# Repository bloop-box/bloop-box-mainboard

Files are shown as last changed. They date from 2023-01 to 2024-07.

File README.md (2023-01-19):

# Bloop Box Mainboard



Mainboard 3D Render

[Documentation](https://bloop-box.github.io/bloop-box-mainboard)

The board is designed using KiCAD 6 with production and assembly by JLCPCB in mind. All parts are selected to be
available from JLCPCB at the time of writing and as many parts as possible are used from their basic library.

- uHAT format (fits on a Raspberry Pi Zero)
- Connectors for:
  - Tailboard (Power supply, buttons, LEDs)
  - SPI NFC-reader (Pinout fitting for *RC522* Module)
  - Speaker
  - I2C connector for LED-Board
  - Additional GPIO header with UART (optional)
- Speaker is driven by a MAX98357 3W amplifier
  - amplifier gain can be set through jumper (9dB default setting)
  - SD_MODE is set to stereo mix by default, solder jumper for setting left-only 

Pinout of all connectors is printed on the bottom of the board

See schematics for detailed GPIO pinout

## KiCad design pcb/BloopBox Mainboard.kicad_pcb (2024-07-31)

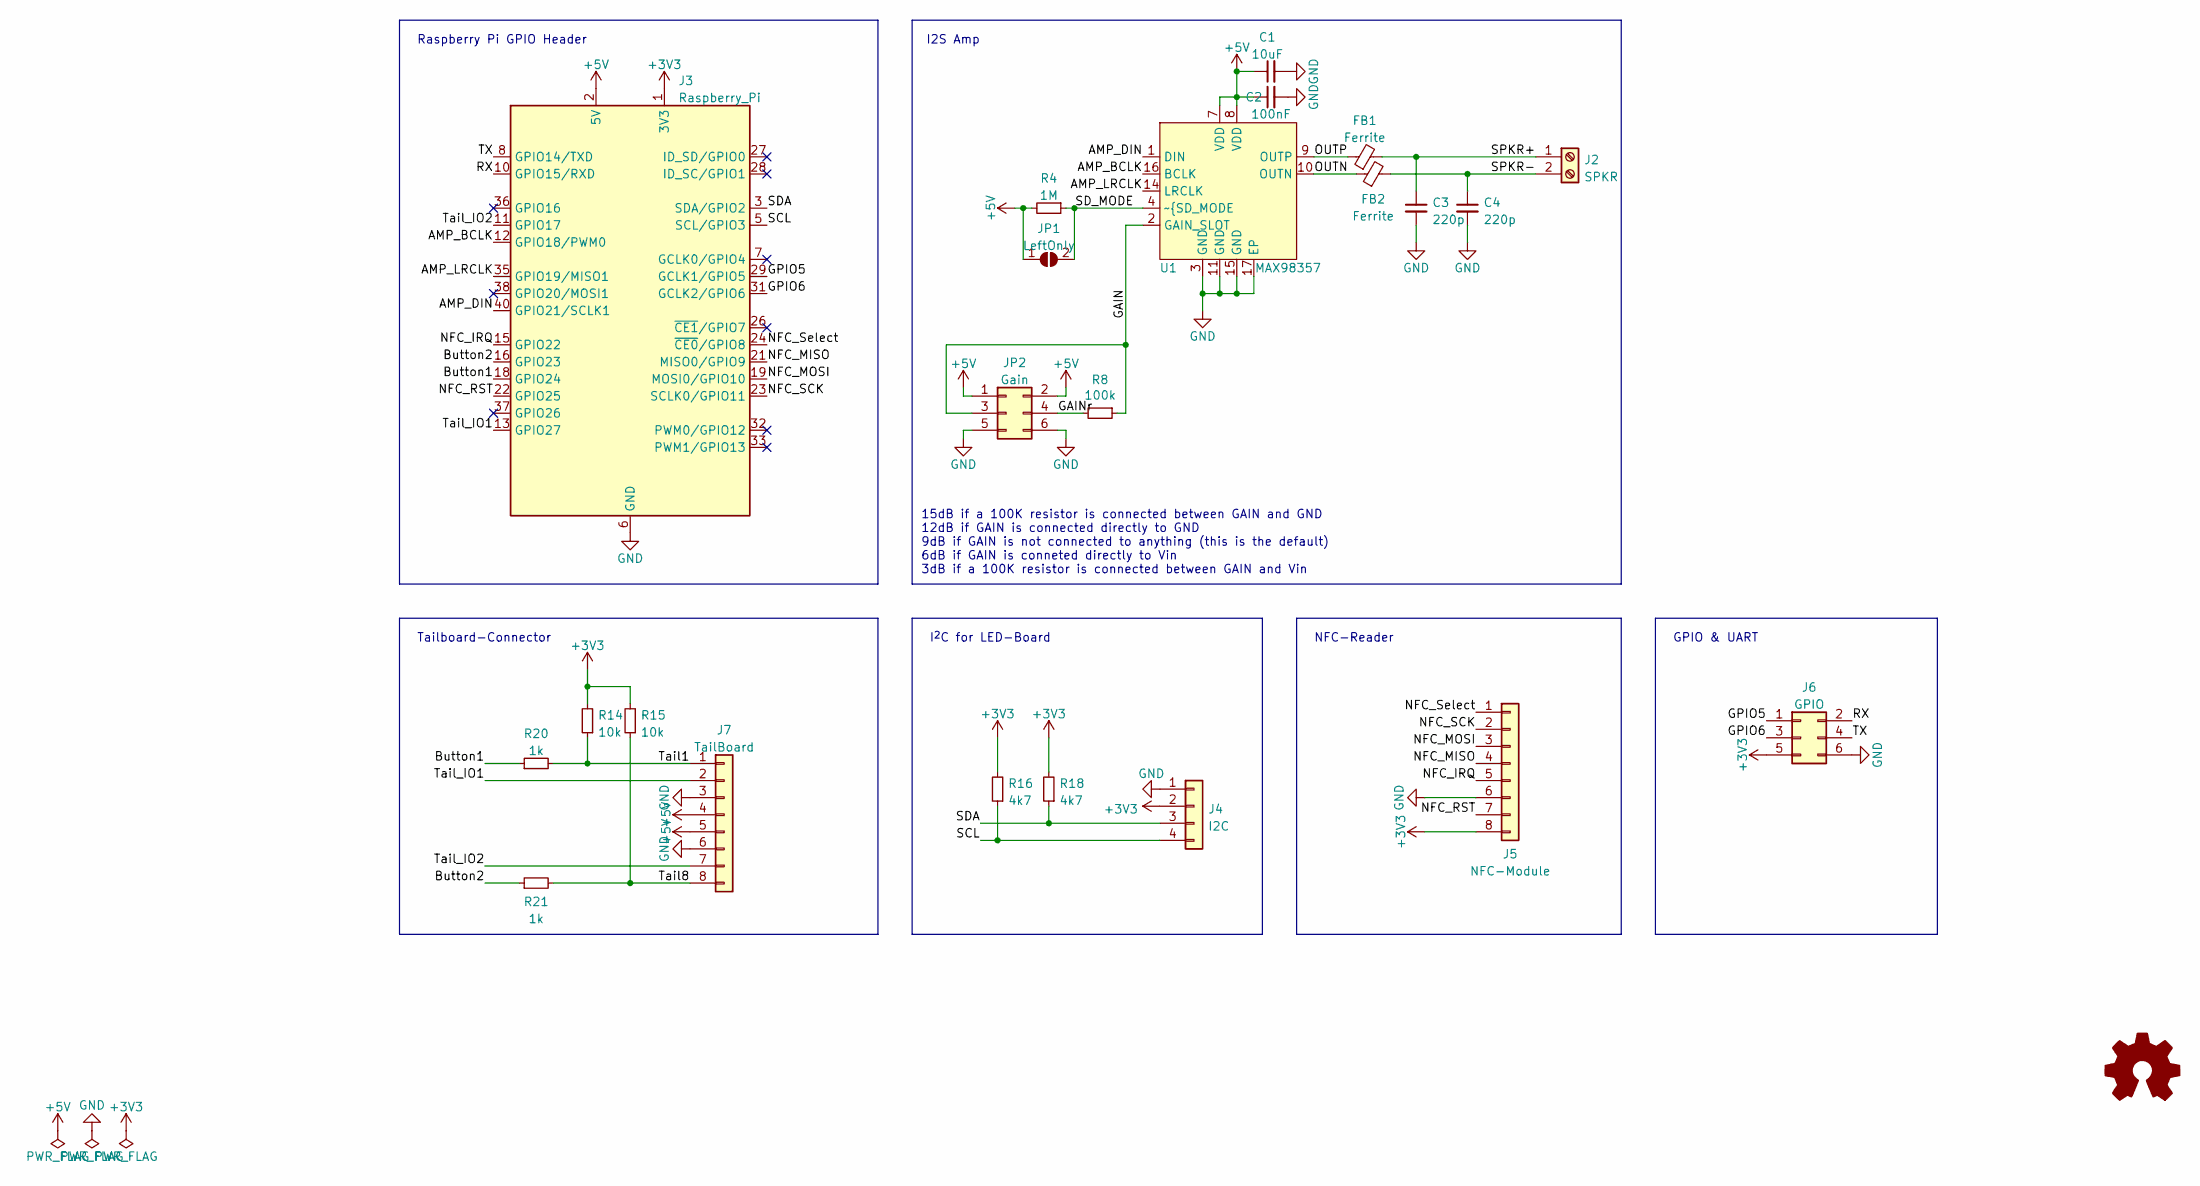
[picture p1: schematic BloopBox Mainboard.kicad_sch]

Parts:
C1: 10uF; C_0805_2012Metric; LCSC C15850
C2: 100nF; C_0402_1005Metric; LCSC C1525
C3, C4: 220p; C_0402_1005Metric; LCSC C1530
FB1, FB2: Ferrite; L_0805_2012Metric; LCSC C1015
J2: SPKR; JST_PH_S2B-PH-K_1x02_P2.00mm_Horizontal; LCSC C49992
J3: Raspberry_Pi; Raspberry_Pi_Zero_Socketed_THT_FaceDown_MountingHoles; LCSC C2977589
J4: I2C; JST_PH_S4B-PH-K_1x04_P2.00mm_Horizontal; LCSC C49994
J5: NFC-Module; JST_PH_S8B-PH-K_1x08_P2.00mm_Horizontal; LCSC C20598766
J6: GPIO; PinHeader_2x03_P2.54mm_Horizontal; LCSC C239334
J7: TailBoard; JST_PH_S8B-PH-K_1x08_P2.00mm_Horizontal; LCSC C20598766
JP1: LeftOnly; SolderJumper-2_P1.3mm_Open_RoundedPad1.0x1.5mm
JP2: Gain; PinHeader_2x03_P2.00mm_Vertical; LCSC C225288
R4: 1M; R_0402_1005Metric; LCSC C26083
R8: 100k; R_0402_1005Metric; LCSC C25741
R14, R15: 10k; R_0402_1005Metric; LCSC C25744
R16, R18: 4k7; R_0402_1005Metric; LCSC C25900
R20, R21: 1k; R_0402_1005Metric; LCSC C11702
U1: MAX98357; TQFN-16-1EP_3x3mm_P0.5mm_EP1.23x1.23mm_ThermalVias; LCSC C910544

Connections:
+3V3: J3.1 (3V3), J3.17 (3V3), J4.2, J5.8, J6.5, R14.2, R15.2, R16.2, R18.2
+5V: C1.1, C2.1, J3.2 (5V), J3.4 (5V), J7.4, J7.5, JP1.1 (A), JP2.1, JP2.2, R4.2, U1.7 (VDD), U1.8 (VDD)
/AMP_BCLK: J3.12 (GPIO18/PWM0), U1.16 (BCLK)
/AMP_DIN: J3.40 (GPIO21/SCLK1), U1.1 (DIN)
/AMP_LRCLK: J3.35 (GPIO19/MISO1), U1.14 (LRCLK)
/Button1: J3.18 (GPIO24), R20.1
/Button2: J3.16 (GPIO23), R21.1
/GAIN: JP2.3, R8.1, U1.2 (GAIN_SLOT)
/GAINr: JP2.4, R8.2
/GPIO5: J3.29 (GCLK1/GPIO5), J6.1
/GPIO6: J3.31 (GCLK2/GPIO6), J6.3
/NFC_IRQ: J3.15 (GPIO22), J5.5
/NFC_MISO: J3.21 (MISO0/GPIO9), J5.4
/NFC_MOSI: J3.19 (MOSI0/GPIO10), J5.3
/NFC_RST: J3.22 (GPIO25), J5.7
/NFC_SCK: J3.23 (SCLK0/GPIO11), J5.2
/NFC_Select: J3.24 (~CE0/GPIO8), J5.1
/OUTN: FB2.1, U1.10 (OUTN)
/OUTP: FB1.1, U1.9 (OUTP)
/RX: J3.10 (GPIO15/RXD), J6.2
/SCL: J3.5 (SCL/GPIO3), J4.4, R16.1
/SDA: J3.3 (SDA/GPIO2), J4.3, R18.1
/SD_MODE: JP1.2 (B), R4.1, U1.4 (~{SD_MODE)
/SPKR+: C3.1, FB1.2, J2.1
/SPKR-: C4.1, FB2.2, J2.2
/TX: J3.8 (GPIO14/TXD), J6.4
/Tail1: J7.1, R14.1, R20.2
/Tail8: J7.8, R15.1, R21.2
/Tail_IO1: J3.13 (GPIO27), J7.2
/Tail_IO2: J3.11 (GPIO17), J7.7
GND: C1.2, C2.2, C3.2, C4.2, J3.6 (GND), J3.9 (GND), J3.14 (GND), J3.20 (GND), J3.25 (GND), J3.30 (GND), J3.34 (GND), J3.39 (GND), J4.1, J5.6, J6.6, J7.3, J7.6, JP2.5, JP2.6, U1.3 (GND), U1.11 (GND), U1.15 (GND), U1.17 (EP)

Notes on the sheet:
I^{2}C for LED-Board
Raspberry Pi GPIO Header
GPIO & UART
I2S Amp
Tailboard-Connector
15dB if a 100K resistor is connected between GAIN and GND 12dB if GAIN is connected directly to GND 9dB if GAIN is not connected to anything (this is the default) 6dB if GAIN is conneted directly to Vin 3dB if a 100K resistor is connected between GAIN and Vin
NFC-Reader

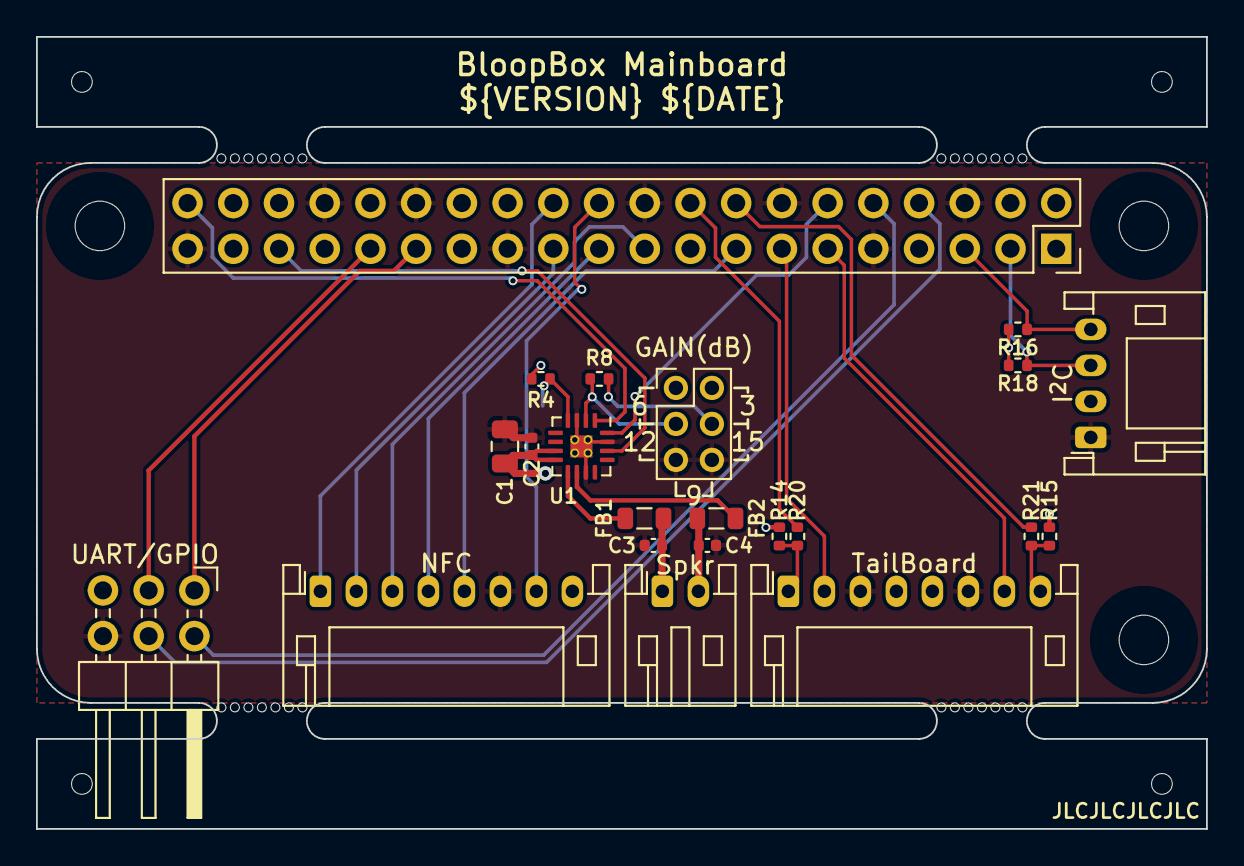
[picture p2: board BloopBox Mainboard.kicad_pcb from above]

Board: 2 copper layers, 65.0 x 44.0 mm, 27 parts (1 on the bottom side), 31 nets.

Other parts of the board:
mouse-bite-2mm-slot, mouse-bite-2mm-slot#2, mouse-bite-2mm-slot#3, mouse-bite-2mm-slot#4: VAL**; mouse-bite-2x5mm-slot-onesided

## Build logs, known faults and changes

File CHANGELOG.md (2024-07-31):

# Changelog

## [2.0.1](https://github.com/bloop-box/bloop-box-mainboard/compare/v2.0.0...v2.0.1) (2024-07-31)

### Bug Fixes

* copper edge clearance ([5cf6c49](https://github.com/bloop-box/bloop-box-mainboard/commit/5cf6c498986e1e9f9c909ac74e83c215b622d0d5))

## [2.0.0](https://github.com/bloop-box/bloop-box-mainboard/compare/v1.0.0...v2.0.0) (2023-01-19)

### ⚠ BREAKING CHANGES

* remove HAT EEPROM
* remove I2C level shifter
* remove RGB LED

### Features

* reduce to two layers ([daa27ec](https://github.com/bloop-box/bloop-box-mainboard/commit/daa27ec4ec4a9b25dcfa96f8c26b65ecf9b1ea43))
* remove HAT EEPROM ([cf92000](https://github.com/bloop-box/bloop-box-mainboard/commit/cf92000fae4ed51b5fee4c6e450fc11b1c285ee3))
* remove I2C level shifter ([b94c306](https://github.com/bloop-box/bloop-box-mainboard/commit/b94c306e1bfe5751c49da7d8ca183a51e0bcca7e))
* remove RGB LED ([2c5ac5f](https://github.com/bloop-box/bloop-box-mainboard/commit/2c5ac5f5aaabc408e38f2fca52ec5572b1a649d2))

### Bug Fixes

* change LCSC part number of I2C pullup ([f7b5855](https://github.com/bloop-box/bloop-box-mainboard/commit/f7b5855fdd118c38ff95c6d2ad4129af0cdf2dad))

## 1.0.0 (2023-01-03)

### ⚠ BREAKING CHANGES

* change NFC connector to RC522 pinout

### Features

* add ID EEPROM ([29fca6b](https://github.com/bloop-box/bloop-box-mainboard/commit/29fca6b0ee6d14b70e27916b70edbddad3c6b2fc))
* add initial eeprom settings and append compilation to release workflow ([c9b4758](https://github.com/bloop-box/bloop-box-mainboard/commit/c9b4758c047ae3c0cc543bdbb0cada0100bebeb2))
* add UART to GPIO-Header ([684cdf3](https://github.com/bloop-box/bloop-box-mainboard/commit/684cdf39494faccde475f5c53999123cf644028c))
* change NFC connector to RC522 pinout ([0ccfcac](https://github.com/bloop-box/bloop-box-mainboard/commit/0ccfcacc2717ffdd54632eade2880b5d04bda1c4))
* more variables ([3ad9d62](https://github.com/bloop-box/bloop-box-mainboard/commit/3ad9d622208fb648b1df063b767c59333f17f956))
* prepare files for automatic version numbering ([8c43f3e](https://github.com/bloop-box/bloop-box-mainboard/commit/8c43f3e3125d3cbd04fc097754fc8e28eb9c87ee))
* remove PWM mosfet ([32390eb](https://github.com/bloop-box/bloop-box-mainboard/commit/32390ebd910076f0735f4e2b29f7aa077e36a9bd))
* split mainboard into standalone repository ([22de539](https://github.com/bloop-box/bloop-box-mainboard/commit/22de539663db7e1ce86aedc6387e2e9298a7a61c))

### Bug Fixes

* 3d-model offset for GPIO connector ([8116aa7](https://github.com/bloop-box/bloop-box-mainboard/commit/8116aa759b54e4d8e2731584663043586e68517e))
* add DATE and VERSION text variables ([80477f6](https://github.com/bloop-box/bloop-box-mainboard/commit/80477f68498f7e7a7a6d753b993b55e98668b47b))
* add default connection for I2C voltage jumper ([9834e36](https://github.com/bloop-box/bloop-box-mainboard/commit/9834e3640ebfb245844be0672dab51fcbe79d453))
* remove Tailboard IO protection resistors ([da9ced2](https://github.com/bloop-box/bloop-box-mainboard/commit/da9ced2ef8a0e79e47c1458d0525a38b68af17bd))
* update nets ([658971c](https://github.com/bloop-box/bloop-box-mainboard/commit/658971c0fbd4f4be307cef0f45213d0d53321734))

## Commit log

2022-12-02 Rename folders
    [BloopBox Mainboard.kicad_pcb, BloopBox Mainboard.kicad_sch]
2022-12-02 ci: add remaining boards to kibot
2022-12-02 chore: remove .kicad_prl files from git
2022-12-03 chore: add KiCAD autosave files to .gitignore
2022-12-03 feat: split mainboard into standalone repository
    [BloopBox Mainboard.kicad_pcb, BloopBox Mainboard.kicad_sch]
2022-12-03 ci: fix path filters
2022-12-03 ci: fix board-file references
2022-12-04 chore: test CI workflow trigger
    [BloopBox Mainboard.kicad_sch]
2022-12-04 build: rename layers to default names
    [BloopBox Mainboard.kicad_pcb]
2022-12-04 feat: prepare files for automatic version numbering
    [BloopBox Mainboard.kicad_pcb, BloopBox Mainboard.kicad_sch]
2022-12-04 feat: more variables
    Using more variables to automate stuff
    [BloopBox Mainboard.kicad_pcb]
2022-12-05 feat: add UART to GPIO-Header
    Adding the UART TX and RX pins to the GPIO header for debugging console access
    [BloopBox Mainboard.kicad_pcb, BloopBox Mainboard.kicad_sch]
2022-12-09 fix: remove Tailboard IO protection resistors
    After removing the PD controller from the tailboard, the LEDs are directly connected to the mainboard so the protection resistors had to go
    [BloopBox Mainboard.kicad_pcb, BloopBox Mainboard.kicad_sch]
2022-12-12 feat!: change NFC connector to RC522 pinout
    Switch the NFC-connector from the PN532 module to the RC522 since the PN532 works not reliable with NTAG
    Connect IRQ and RST lines while doing so
    [BloopBox Mainboard.kicad_pcb, BloopBox Mainboard.kicad_sch]
2022-12-12 docs: update README
    NFC header changed to RC522
    UART added
2022-12-12 feat: add ID EEPROM
    Add (optional) ID EEPROM to the board that will allow some of the hardware to be auto-configured on the Raspberry Pi.
    [BloopBox Mainboard.kicad_pcb, BloopBox Mainboard.kicad_sch]
2023-01-03 feat: remove PWM mosfet
    didnt work as hoped so it gets removed
    [BloopBox Mainboard.kicad_sch]
2023-01-03 fix: update nets
    [BloopBox Mainboard.kicad_pcb]
2023-01-03 fix: add default connection for I2C voltage jumper
    [BloopBox Mainboard.kicad_pcb, BloopBox Mainboard.kicad_sch]
2023-01-03 fix: 3d-model offset for GPIO connector
    [BloopBox Mainboard.kicad_pcb]
2023-01-18 feat!: remove RGB LED
    remove the RGB LED facilities since we're using I2C for that now
    [BloopBox Mainboard.kicad_pcb, BloopBox Mainboard.kicad_sch]
2023-01-19 style: remove disused silkscreen elements
    [BloopBox Mainboard.kicad_pcb]
2023-01-19 feat!: remove I2C level shifter
    The new LED driver needs 3.3V I2C anyway so the level shifter is not needed anymore.
    [BloopBox Mainboard.kicad_sch]
2023-01-19 feat: reduce to two layers
    After removing some optional and deprecated hardware the board can be reduced to 2 layers to save production cost
    [BloopBox Mainboard.kicad_pcb]
2023-01-19 feat!: remove HAT EEPROM
    Since it is more effort to program each EEPROM after assembly than manually changing the settings it could handle, the EEPROM would only be a novelty and was removed.
    [BloopBox Mainboard.kicad_pcb, BloopBox Mainboard.kicad_sch]
2023-01-19 fix: change LCSC part number of I2C pullup
    [BloopBox Mainboard.kicad_pcb, BloopBox Mainboard.kicad_sch]
2023-01-19 chore: remove EEPROM workflow
    The EEPROM was removed from the board, so we don't need the workflow and the settings file anymore.
2023-07-30 chore: update to KiCad 7
    [BloopBox Mainboard.kicad_pcb, BloopBox Mainboard.kicad_sch]
2024-07-31 chore: update to KiCad 8
    [BloopBox Mainboard.kicad_pcb, BloopBox Mainboard.kicad_sch]
2024-07-31 fix: copper edge clearance
    [BloopBox Mainboard.kicad_pcb]
2024-07-31 docs: remove wrong 3d model from footprint
    [BloopBox Mainboard.kicad_pcb]
